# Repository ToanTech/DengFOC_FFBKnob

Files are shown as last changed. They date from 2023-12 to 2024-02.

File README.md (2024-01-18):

# DengFOC_FFBKnob

灯哥开源力反馈旋钮 是基于DengFOC V4驱动板开发的一个开源小巧无刷力控旋钮应用套件。
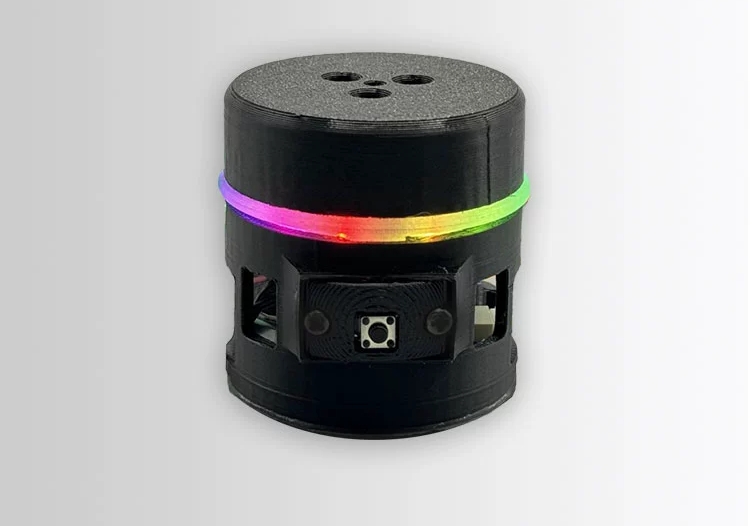
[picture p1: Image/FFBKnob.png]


## 演示视频
[旋钮演示视频](https://www.bilibili.com/video/BV19C4y1X7oA)

## 介绍

该开源项目基于 DengFOC V4驱动板开发。
如对本项目感兴趣，可以在我们[灯哥开源店铺](https://shop564514875.taobao.com/)里搜索 **力反馈旋钮** 购买。  
您的支持就是我们持续做开源内容和课程的动力，项目收益将用于后续开发DengFOC和做课程~

本项目使用[DengFOC V4无刷电机驱动板](http://dengfoc.com/#/dengfoc/DengFOC%E5%AE%98%E6%96%B9%E7%A1%AC%E4%BB%B6/1%E9%A9%B1%E5%8A%A8%E5%99%A8/1.1V4)通过DengFOC库来实现来实现旋钮的力反馈效果，并能够像微软的Surface Dial那样控制电脑的功能。此外，它还可以根据旋钮模式展现各种灯效。

- 硬件方案说明  
  力反馈旋钮由四个模块组成，分别为 DengFOC V4驱动板、磁编码器模块、RGB模块以及按键模块。  
  DengFOC V4驱动板是最主要的模块，该模块集成了ESP32主控，实现对各路模块和电机的控制，其中包括①板上逆变电路控制电机；②通过IIC读取编码器模块的电机角度信息；③通过单线串码控制RGB模块中每盏RGB灯的亮度以及颜色；④读取按键电平状态。

- 软件方案说明  
  开发环境：Arduino IDE  
  引用库：  
    + [DengFOC V0.4 开源电机驱动库详情点击查看](https://github.com/ToanTech/DengFOC_Lib/)  
    + DFOC_RGB   
    + OneButton
    + Blekeyboard

- 后续计划   
  + 增加更多酷炫的灯效  
  + 按键更改不同的盖帽  

## 特性

- 无刷电机力反馈效果
- 基于DengFOC V0.4 开源电机驱动库
- 支持控制电脑
- 支持多种灯效

## 仓库说明
- Src-力反馈旋钮实现代码
- Hardware-硬件，机械结构相关资料。包含3D打印文件，相关模块原理图、BOM等
- Docs-相关文档，包含安装文档，软件安装等
- Images

## 准备

硬件：
 - DengFOC V4驱动板（含INA240电流传感器）
 - 2208电机   
 - AS5600编码器
 - WS2812B光环
 - 轻触开关
 - SH1.0 5P线、GH1.25 4P线
 - 铜柱、螺丝若干

软件：
 - Arduino IDE或PlatformIO
 - Vofa +

## 搭建

- 力反馈旋钮安装  
详看本仓库Docs->安装文档

- 程序编译和下载  
  软件安装详看Docs->软件安装  
  程序代码详看本仓库Src

## 免费力反馈旋钮原理教学课程
  + [课时1 概论和课程简介](https://www.bilibili.com/video/BV18K411t7Wd/?vd_source=5d20af79ff500db9da1b6e7e1213da51)
  + [课时2  机械结构设计和DIY组装](https://www.bilibili.com/video/BV1d64y1K7nG/)
  + 课时3 旋钮力控功能实现-棘轮模式
  + 课时4 旋钮力控功能实现-边界模式
  + 课时5 旋钮力控功能实现-顺滑阻尼模式
  + 课时6 旋钮其他功能实现-按键、灯效
  + 课时7 旋钮其他功能实现-控制电脑

## 技术支持
为了更好地服务购买本产品的客户，我们设立了一个专门的售后群，用于解决客户在使用过程中遇到的问题。此外，我们还会定期发布有关产品的最新动态，以及有关产品的使用技巧，以帮助客户更好地了解产品，提高使用效率。Q群号：450913932

## 许可证
This project is licensed under the GPL-2.0 license

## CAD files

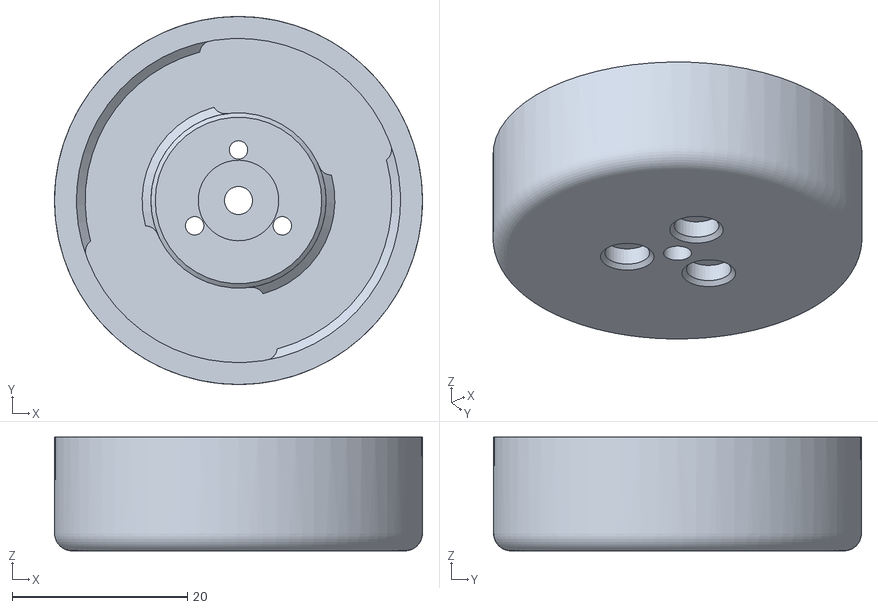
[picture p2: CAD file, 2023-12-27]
Hardware/模型/打印件/旋钮盖子.STL
42.0 x 42.0 x 13.0

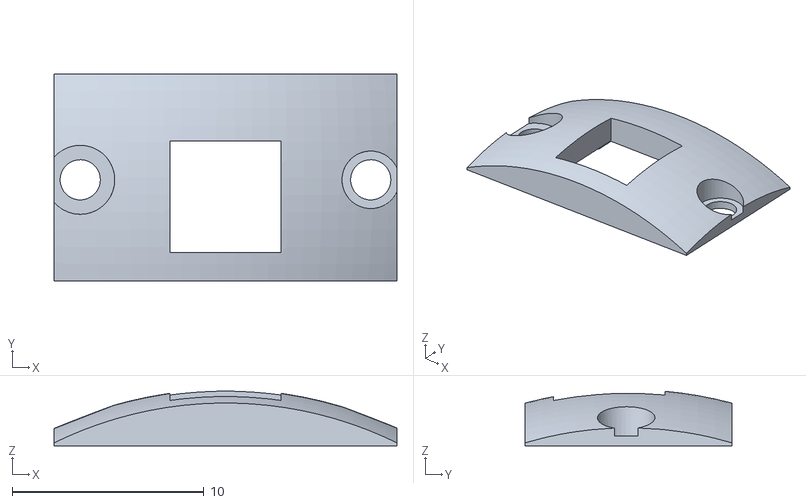
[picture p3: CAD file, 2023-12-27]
Hardware/模型/打印件/按钮盖4.5×4.5mm.STL
17.9 x 10.8 x 2.85

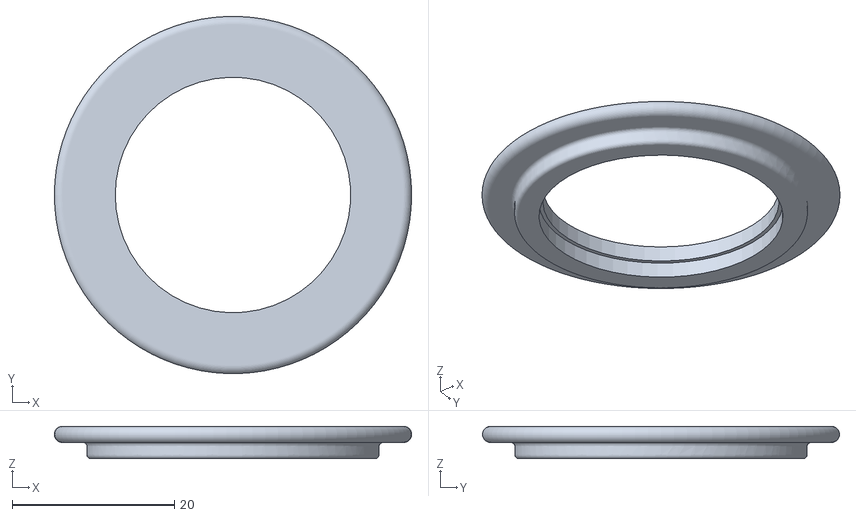
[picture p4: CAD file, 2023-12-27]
Hardware/模型/打印件/knob_ring.STL
44.0 x 44.0 x 4.00

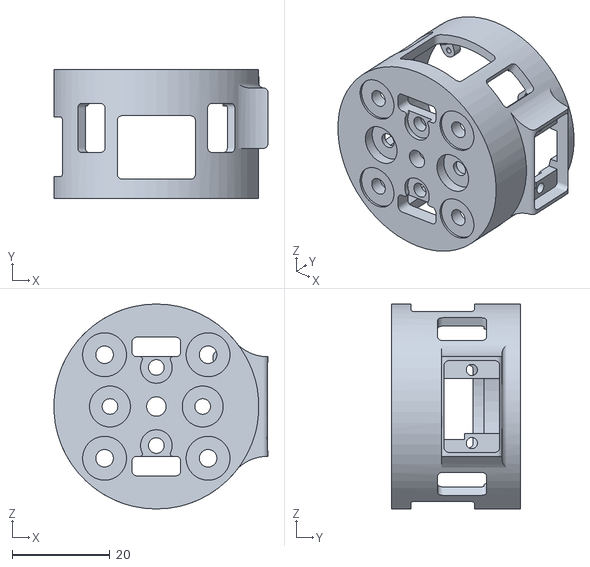
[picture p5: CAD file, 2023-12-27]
Hardware/模型/打印件/外壳.STL
43.8 x 26.5 x 42.0

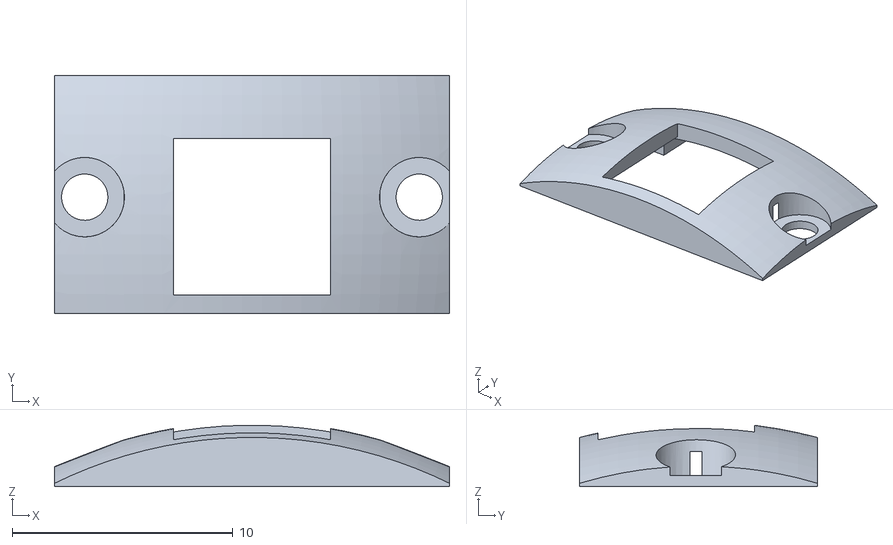
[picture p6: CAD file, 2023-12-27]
Hardware/模型/打印件/按钮盖6×6mm.STL
17.9 x 10.8 x 2.78

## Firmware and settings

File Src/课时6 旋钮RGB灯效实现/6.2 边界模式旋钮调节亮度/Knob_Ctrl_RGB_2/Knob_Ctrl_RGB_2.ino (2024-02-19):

// 例程2：60分度棘轮，360°边界下，旋钮调节亮度
// 可切换为:
//     无极-边界
//     棘轮边界

// DengFOC V0.2
// 灯哥开源，遵循GNU协议，转载请著名版权！
// GNU开源协议（GNU General Public License, GPL）是一种自由软件许可协议，保障用户能够自由地使用、研究、分享和修改软件。
// 该协议的主要特点是，要求任何修改或衍生的作品必须以相同的方式公开发布，即必须开源。此外，该协议也要求在使用或分发软件时，必须保留版权信息和许可协议。GNU开源协议是自由软件基金会（FSF）制定和维护的一种协议，常用于GNU计划的软件和其他自由软件中。
// 仅在DengFOC官方硬件上测试过，欢迎硬件购买/支持作者，淘宝搜索店铺：灯哥开源
// 你的支持将是接下来做视频和持续开源的经费，灯哥在这里先谢谢大家了

#include "DengFOC.h"
#include "DFOC_RGB.h"

#define _2PI 6.28318530718f
/********************************************/
// 0为无极-边界
// 1为棘轮-边界
#define MODE 1  // 选择棘轮边界模式
/********************************************/
int Sensor_DIR = 1;  // 传感器方向，若电机运动不正常，将此值取反
int Motor_PP = 7;    // 电机极对数
void Detents_Mode(void);
/********************************************/
// 参数设置
float kp_pos1 = 20;
float kp_pos2 = 20;       // 4->20,加大力度
float anlge_range = 360;  // 边界范围360°，限制为1圈
float zero_angle = 0;     // 零点位置
/********************************************/
DFOC_RGB RGB = DFOC_RGB();
/********************************************/
void setup() {
  Serial.begin(115200);
  pinMode(12, OUTPUT);
  digitalWrite(12, HIGH);  // 使能，一定要放在校准电机前

  DFOC_Vbus(12.6);  // 设定驱动器供电电压
  DFOC_alignSensor(Motor_PP, Sensor_DIR);
  // zero_angle = DFOC_M0_Angle();  // 将当前位置设置为零点
  zero_angle = 3.14;  //亮度的角度是限制在0~6.28，所以边界的中值固定为3.14

  RGB.begin();  // RGB程序初始化
}

void loop() {
  runFOC();
  float angle = DFOC_M0_Angle();
  float angle_range2 = anlge_range / 2;
  float limit_range = angle_range2 / 360.0f * _2PI;
  float L1 = zero_angle + limit_range;
  float L2 = zero_angle - limit_range;
  // angle_range 范围内
  if (angle > L2 && angle < L1) {
    if (MODE == 0)
      DFOC_M0_setTorque(0);
    else if (MODE == 1)
      Detents_Mode();
  } else {  // angle_range 范围外
    if (angle < L2)
      DFOC_M0_setTorque(kp_pos1 * (L2 - angle));
    if (angle > L1)
      DFOC_M0_setTorque(kp_pos1 * (L1 - angle));
  }

  RGB.bri_Adj(angle, 255, 0, 0);  // 旋钮调节亮度
}

// 60细分度
void Detents_Mode(void) {
  float attractor_distance = 6 * 3.1415926 / 180.0;
  float target = round(DFOC_M0_Angle() / attractor_distance) * attractor_distance;
  DFOC_M0_setTorque(kp_pos2 * (target - DFOC_M0_Angle()));
}

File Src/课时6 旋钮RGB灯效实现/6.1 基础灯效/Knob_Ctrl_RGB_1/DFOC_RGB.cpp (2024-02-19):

#include "DFOC_RGB.h"
// 自定义颜色
// 可以参考以下网址 https://www.rapidtables.org/zh-CN/web/color/RGB_Color.html
// RGB.setColor(0, 188, 40, 40);  //红色 [索引号0，R,G,B] ,具体颜色可以参考网址里的颜色表

// 初始化设置
DFOC_RGB::DFOC_RGB()
{
  ledCounts = 10;   // 灯珠的数量
  pin = 15;         // RMT输出的引脚，即驱动RGB的IO口
  brightness = 120; // 初始亮度

  rmt_mem = RMT_MEM_64; // RMT内存设置

  r_pos = 1;
  g_pos = 0;
  b_pos = 2;
}

// RMT通道设置
bool DFOC_RGB::begin()
{
  if ((rmt_send = rmtInit(pin, true, rmt_mem)) == NULL)
  {
    return false;
  }
  for (int i = 0; i < ledCounts; i++)
  {
    for (int bit = 0; bit < 24; bit++)
    {
      led_data[i * 24 + bit].level0 = 1;
      led_data[i * 24 + bit].duration0 = 4;
      led_data[i * 24 + bit].level1 = 0;
      led_data[i * 24 + bit].duration1 = 8;
    }
  }
  realTick = rmtSetTick(rmt_send, 100);
  return true;
}

void DFOC_RGB::setColor(int index, u8 brightness, u32 rgb)
{
  setColor(index, brightness, rgb >> 16, rgb >> 8, rgb);
}

// 遍历设置像素颜色
void DFOC_RGB::set_pixel(int index, u8 r, u8 g, u8 b)
{
  u32 color = r << 16 | g << 8 | b;
  // delayMicroseconds(300);
  for (int bit = 0; bit < 24; bit++)
  {
    if (color & (1 << (23 - bit)))
    {
      led_data[index * 24 + bit].level0 = 1;
      led_data[index * 24 + bit].duration0 = 8;
      led_data[index * 24 + bit].level1 = 0;
      led_data[index * 24 + bit].duration1 = 4;
    }
    else
    {
      led_data[index * 24 + bit].level0 = 1;
      led_data[index * 24 + bit].duration0 = 4;
      led_data[index * 24 + bit].level1 = 0;
      led_data[index * 24 + bit].duration1 = 8;
    }
  }
}

// 设置好的led数据写入
void DFOC_RGB::show()
{
  rmtWrite(rmt_send, led_data, ledCounts * 24);
}

/************************************************灯效************************************************/
// index: 每盏RGB索引号
// brightness：亮度
// R、G、B: RGB三色值
// 设定红绿蓝三通道的颜色值
void DFOC_RGB::setColor(int index, uint8_t brightness, uint8_t R, uint8_t G, uint8_t B)
{
  u8 p[3];
  p[r_pos] = R * brightness / 255;
  p[g_pos] = G * brightness / 255;
  p[b_pos] = B * brightness / 255;
  set_pixel(index, p[0], p[1], p[2]);
}

// 灯环所有灯的统一控制
void DFOC_RGB::setAllcolor(int brightness, uint8_t R, uint8_t G, uint8_t B)
{
  for (int i = 0; i < ledCounts; i++)
  {
    setColor(i, brightness, R, G, B);
  }
  show(); // 显示更新后的颜色
}

static unsigned long blink_counter = 0;
static bool blink_done = false;
bool DFOC_RGB::blink(u8 times, int brightness, uint8_t R, uint8_t G, uint8_t B)
{
  unsigned long current_time = millis();
  static unsigned long prev_time = 0;

  // 定时器
  if (current_time - prev_time > 300)
  {
    prev_time = current_time;
    if (blink_counter >= times * 2)
      blink_done = true;
    else
    {
      if ((blink_counter % 2) == 0)
        setAllcolor(brightness, R, G, B);
      else
        setAllcolor(0, 0, 0, 0);
      blink_counter++;
    }
  }
  if (blink_done)
    return true;
  return false;
}

// 下次blink之前，切换状态后要reset blink的参数
void DFOC_RGB::blink_reset()
{
  blink_done = false;
  blink_counter = 0;
}

void DFOC_RGB::breath(int interval, uint8_t R, uint8_t G, uint8_t B)
{
  unsigned long current_time = millis();
  static unsigned long prev_time = 0;
  static unsigned int brightness = 0;
  static bool turn_flag = true;

  // 定时器
  if (current_time - prev_time > interval)
  {
    prev_time = current_time;
    setAllcolor(brightness, R, G, B);
    if (turn_flag)
    {
      brightness++;
      if (brightness >= 255)
        turn_flag = false;
    }
    else
    {
      brightness--;
      if (brightness <= 0)
        turn_flag = true;
    }
  }
}

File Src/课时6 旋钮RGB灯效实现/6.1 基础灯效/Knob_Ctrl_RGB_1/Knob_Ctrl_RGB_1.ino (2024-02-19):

//  例程1：基础灯效
//  DengFOC V0.2
//  灯哥开源，遵循GNU协议，转载请著名版权！
//  GNU开源协议（GNU General Public License, GPL）是一种自由软件许可协议，保障用户能够自由地使用、研究、分享和修改软件。
//  该协议的主要特点是，要求任何修改或衍生的作品必须以相同的方式公开发布，即必须开源。此外，该协议也要求在使用或分发软件时，必须保留版权信息和许可协议。GNU开源协议是自由软件基金会（FSF）制定和维护的一种协议，常用于GNU计划的软件和其他自由软件中。
//  仅在DengFOC官方硬件上测试过，欢迎硬件购买/支持作者，淘宝搜索店铺：灯哥开源
//  你的支持将是接下来做视频和持续开源的经费，灯哥在这里先谢谢大家了

#include "DFOC_RGB.h"

DFOC_RGB RGB = DFOC_RGB();

void setup() {
  RGB.begin();  // RGB程序初始化
}

void loop() {
  unsigned long current_time = millis();
  static unsigned long prev_time = 0;

  /**********************************************************/
  // 灯效1：单独点亮第二个LED灯珠
  // RGB.setColor(0, 100, 255, 255, 0);
  // RGB.show(); // 只设置一个灯需要show函数
  // delay(1);   // 需要280μs以上的Reset信号
  /**********************************************************/
  // 灯效2：点亮一圈
  // RGB.setAllcolor(100, 255, 255, 0); // show封在函数里面了
  // delay(1);                          // 需要280μs以上的Reset信号
  /**********************************************************/
  // 灯效3：闪烁2次后点亮一圈，间隔5s后重复操作
  // if (RGB.blink(2, 100, 255, 255, 0))  // blink不需要延时是因为，实现blink灯效的时候有300ms的时间间隔
  // {
  //   RGB.setAllcolor(100, 0, 255, 0);  // 点亮一圈
  //   delay(1);                         // 需要280μs以上的Reset信号
  // }
  // if (current_time - prev_time > 5000) {
  //   prev_time = current_time;
  //   RGB.blink_reset();  // 重新闪烁
  // }
  /**********************************************************/
  // 灯效4：呼吸灯
  RGB.breath(5, 0, 0, 255);
}
